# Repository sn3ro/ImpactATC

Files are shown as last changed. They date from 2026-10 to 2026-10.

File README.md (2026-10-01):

# ImpactATC

**Macros, integration examples, and user-modifiable components for the ImpactATC automatic tool changer.**

ImpactATC is a CNC automatic tool change system that uses an **impact driver mechanism** to generate the torque required for tightening and loosening the collet nut. This approach enables higher and more consistent torque compared to typical hobby ATC systems. At its default settings, ImpactATC tightens the ER20 nut to around 35Nm.

This repository provides the **essential files needed to integrate and use ImpactATC**, including CNC macros and selected user-serviceable hardware components.

---

## 📦 What’s in this repository

- CNC macros for tool changing (e.g. LinuxCNC)
- Basic integration examples
- Selected 3D-printable parts for user interfacing (e.g. nut holder)

This repository **does not contain the full mechanical design** of ImpactATC.

---

## 📁 Repository Structure (once all the files are added)

```markdown
ImpactATC/
├─ macros/            # CNC tool-change macros and control logic
│  ├─ linuxcnc/       # LinuxCNC-specific macros (M6, subroutines, HAL)
│  └─ README.md       # Notes on usage and configuration
│
├─ hardware/          # User-modifiable hardware components only
│  ├─ step/           # Printable / reference CAD (e.g. ER20 nut holder)
│  └─ README.md       # Scope, print settings and limitations
│
├─ docs/              # Basic setup and integration guidance
│  └─ setup.md        # Initial setup instructions
│
└─ README.md
```
---

## ⚙️ How It Works

ImpactATC uses a mechanism inspired by an **impact driver**:

- Rotational energy is accumulated and released in controlled impacts  
- These impacts generate high peak torque  
- This enables reliable tightening and loosening of the collet nut  

This method provides improved performance over systems relying on friction or limited mechanical leverage.

---

## 🛠 Getting Started

1. Download the required macros from `macros/`  
2. Print any required parts from `hardware/` — see [`hardware/README.md`](hardware/README.md) for
   materials and print settings (the ER20 nut holder is PETG, Strength profile, 100% infill)  
3. Follow setup instructions in `docs/`  
4. Integrate with your CNC controller  

---

## 🔒 Notes on Design Files

Only a subset of hardware files is included in this repository.

These are provided to:
- Allow integration with ImpactATC
- Enable user modification of interface components

They are **not a complete representation of the system design**.

---

## ⚠️ Safety

ImpactATC involves high torque and dynamic mechanical loading.

- Test carefully at low speeds  
- Ensure all components are securely mounted  
- Use appropriate guarding and PPE  

You are responsible for the safe operation of your machine.

---

## 📜 License

This project is licensed under the **MIT License**.

You are free to use, modify, and adapt the provided files.  
See the `LICENSE` file for details.

---

## 📬 Feedback

If you have questions or suggestions, feel free to open an Issue.

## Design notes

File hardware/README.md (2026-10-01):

# Hardware

User-serviceable parts only. This is **not** the full mechanical design of ImpactATC — see the note
in the top-level [README](../README.md).

## What's here

| File | Part |
|---|---|
| `step/ImpactATC-ER20-Nut-holder.step` | ER20 nut holder |

STEP is supplied rather than STL because slicers such as Bambu Studio and Orca open STEP directly,
and it stays useful if you want to modify the part.

---

## ER20 nut holder

The nut holder transfers torque from the module directly onto the ER20 collet nut.

It is a **wear part**. Expect to replace it after a few hundred tool-change cycles — it is meant to
be the component that wears, so print spares and keep one on the shelf.

### Print settings

| Setting | Value |
|---|---|
| Material | **PETG** |
| Profile | Bambu Studio **Strength** preset |
| Infill | **100%** |

The part is under repeated impact loading, so the 100% infill and the Strength profile both matter —
a standard or draft profile will not survive. Do not substitute PLA.

### Printing it

1. Open `step/ImpactATC-ER20-Nut-holder.step` directly in Bambu Studio (or your slicer of choice).
2. Select the **Strength** profile and a PETG filament.
3. Set infill to **100%**.
4. Slice and print.

### Replacing it

Replacement is covered by the disassembly sequence: remove the top dust cover, lift out the old nut
holder and the spring beneath it, fit the new holder, and reassemble in reverse.

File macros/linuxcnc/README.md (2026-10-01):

# ImpactATC macros for LinuxCNC

The **reference implementation**. The load and unload sequences here are the ones run daily on the
development machine (LinuxCNC on a Remora-converted EC300); every other dialect is ported from them.

---

## Files

| File | Purpose | Needed? |
|---|---|---|
| `impactatc_tool_loading.ngc` | Load a tool — screws the collet nut on | **Yes** |
| `impactatc_tool_unloading.ngc` | Unload a tool — unscrews the collet nut | **Yes** |
| `impactatc_check_loaded.ngc` | Confirms a tool is in the spindle after a load | Optional — needs a beam sensor |
| `impactatc_check_unloaded.ngc` | Confirms the spindle is empty after an unload | Optional — needs a beam sensor |

For automatic changes on `M6`, see [`m6-integration/`](m6-integration/) once these are commissioned.

All four ship as **standalone programs**: open one in AXIS / gmoccapy / QtDragon and run it like any
other program. That is the commissioning step — see [setup.md, stage 5](../../docs/setup.md#5-commission).

---

## Installing

Copy the files into a folder listed in `SUBROUTINE_PATH` in your INI's `[RS274NGC]` section — for
example:

```ini
[RS274NGC]
SUBROUTINE_PATH = macros
```

**Keep the filenames lowercase.** LinuxCNC lower-cases `o<name>` when it looks a subroutine file
up, so a file with capitals in its name cannot be called once you integrate. Don't rename them.

---

## Setting it up

Each macro has a **SET ME** block at the top. The values ship as `9999`, and the macro **aborts
with a message** until you replace them — it will not drive anywhere with placeholder coordinates.

| Parameter | In | What it is |
|---|---|---|
| `#<z_reference>` | load, unload | Machine Z where the spindle, **with no collet nut fitted**, just touches the top face of the module. About −62 on the development machine — yours will differ |
| `#<pocket_x>` / `#<pocket_y>` | load, unload | Machine XY of the pocket centre, measured with the nut fitted |
| `#<sensor_x>`, `#<beam_x>`, `#<sensor_y>`, `#<z_check>` | both checks | Sensor approach position, in-beam X, and the Z where your shortest tool still breaks the beam |
| `#<beam_broken_val>` | both checks | What `#5399` reads with the beam broken. `1` on the development machine; confirm yours in Halshow |

Measure them as described in [calibration.md](../../docs/calibration.md). The load and unload values
**must be identical** — a mismatch is the classic cause of a module that loads and then misses on
unload. The same goes for the two check macros.

Everything else — speeds, feeds, dwells, engagement depths — is the production configuration.
See [parameters.md](../../docs/parameters.md) before changing any of it, and note that the unscrew
speed (1250) is **deliberately** higher than the tightening speed (1100).

---

## Commissioning

Hand on the E-stop throughout. Follow [setup.md](../../docs/setup.md#5-commission); in short:

1. Dry-run the spindle: `M3 S900`, `M3 S1100`, `M4 S300`, `M4 S1250`. **M4 must reverse.**
2. Fill in the SET ME blocks. Run each macro once with values still at `9999` and confirm it aborts —
   that proves the guard works on your install.
3. Walk the Z moves by hand at the pocket, spindle stopped.
4. Run **unload** first, with a nut and tool in the spindle. Then **load**.
5. Alternate them for several cycles and watch for drift.

### Optional: tool presence sensor

The check macros read a through-beam sensor (developed with an Autonics BUP-50 fork sensor) on
`motion.digital-in-00`, using `M66 P0 L0`. Your HAL needs one line; the input pin name depends on
your hardware:

```hal
net tool-present motion.digital-in-00 <= <your-input-pin>
```

`motion.digital-in-00` exists by default (motmod creates four). Then:

1. Open Halshow, watch `motion.digital-in-00`, and break the beam by hand. If broken reads `0`, set
   `#<beam_broken_val> = 0` in both check macros.
2. With a tool loaded, run `impactatc_check_loaded.ngc` — it should complete silently.
3. With the spindle empty, run `impactatc_check_unloaded.ngc` — it should complete silently.
4. Hold a chip or a strip of card in the fork and run either one — it must abort with
   *beam blocked before check*.

A dead sensor stuck at "clear" cannot be caught by the unload check (clear is the expected answer);
the load check catches it on the next load.

---

## Integrating with M6

Only once the standalone macros work reliably.

**Converting a macro to a subroutine:** uncomment the `o<...> sub` and `o<...> endsub` lines and
delete the final `M2`. It can then be called as `o<impactatc_tool_unloading> call` from your
`M6` remap (`REMAP=M6 ... ngc=...` in the INI).

How the development machine does it, and the lessons from doing it:

- **Tool numbering** — manual tools in pockets 1–60, ATC pockets 61 and up. The remap compares the
  current and requested pockets to pick one of four cases: manual→manual, manual→ATC, ATC→manual,
  ATC→ATC. See [tool-numbering.md](../../docs/tool-numbering.md).
- **Pocket coordinates live in the remap**, which moves over the pocket and then calls load or
  unload. With several modules, remove the XY move and the pocket SET ME lines from the load/unload
  subroutines so there is only one copy of each coordinate. Keep `z_reference` in both.
- **Abort on an unknown pocket.** If the requested pocket has no coordinates, the remap must
  `(ABORT, ...)` — never fall back to a default position and run the cycle there. Adding a module
  and forgetting its coordinates should stop the machine, not plunge the spindle somewhere else.
- **Travel along a safe lane.** Retract to safe Z and move along a Y (or X) that clears every
  module before going over the pocket.
- **Call the checks straight after each load / unload**, while still near the changer.
- **Update the tool number after an ATC→ATC change** with `M61 Q<tool>`; the builtin `M6` does it
  in the cases that end in a manual change.
- **After any abort**, LinuxCNC's idea of the loaded tool may be wrong. Fix the physical problem,
  then set the true state with `M61 Q<n>` (`M61 Q0` for an empty spindle) before running anything.

A complete, ready-to-configure remap built on these lessons is in [`m6-integration/`](m6-integration/).

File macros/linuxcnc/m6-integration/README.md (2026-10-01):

# ImpactATC M6 integration for LinuxCNC

An `M6` remap that changes tools automatically between ImpactATC modules, and by hand for any tool
that does not live in a module.

> **Status: for testing.** The sequence is the one used daily on the development machine, but this
> generic package has not yet been through a validation campaign on hardware. It has been run
> through the LinuxCNC 2.9 interpreter in simulation — all four cases, the configuration guards,
> and the sensor and cover options. Commission it with the test sequence below, hand on the E-stop.

> **Do this last.** Only start here once the standalone macros in [`../`](../) load and unload
> reliably on your machine. See [setup.md](../../../docs/setup.md#6-integrate).

---

## What it does

When your program calls `M6`, LinuxCNC runs `impactatc_m6.ngc` instead of its built-in tool change.
It looks at the **P (pocket)** column of the tool table for the tool in the spindle and the tool
requested:

| P | Meaning |
|---|---|
| 1–60 | Manual tool. Changed by hand at the manual change position |
| 61–66 | Lives in that ImpactATC module (61 = first module, 62 = second, …) |

and picks one of four cases:

| Case | What happens |
|---|---|
| manual → manual | Goes to the manual change position, LinuxCNC's normal tool-change prompt |
| manual → ATC | Manual stop to **empty** the spindle (skipped if it is already empty), then the ATC loads the new tool |
| ATC → manual | ATC unloads the current tool, then manual stop to insert the new one (skipped for `T0`) |
| ATC → ATC | ATC unloads into one module, then loads from the other |

Travel to and from the modules goes along a **safe lane** you define, so a tool hanging below the
spindle never passes over a module.

### Safety behaviour

The remap **aborts before anything moves** if:

- any required value in the config is still `9999`
- a tool's P number is 61–66 but that module has no coordinates (or P is above 66)
- an ATC → ATC change has both tools assigned to the **same module** — unloading one and loading
  "the other" would just reload the same tool, with the wrong tool length

With the optional sensor fitted it also aborts if the spindle is not empty after an unload, not
loaded after a load, or the sensor is blocked by a chip.

---

## Files

| File | Edit it? | Purpose |
|---|---|---|
| `impactatc_m6_config.ngc` | **Yes — the only one** | All your machine's values |
| `impactatc_m6_after_change.ngc` | Optional | Your hook, e.g. tool-length measurement |
| `impactatc_m6.ngc` | No | The remap — decides the case and runs it |
| `impactatc_m6_load.ngc` | No | Load sequence (production values) |
| `impactatc_m6_unload.ngc` | No | Unload sequence (production values) |
| `impactatc_m6_pocket_xy.ngc` | No | Pocket lookup — aborts on unknown pockets |
| `impactatc_m6_lane.ngc` | No | Safe-lane travel |
| `impactatc_m6_check.ngc` | No | Optional beam-sensor check |
| `impactatc_m6_cover.ngc` | No | Optional powered cover |
| `python/toplevel.py`, `python/remap.py` | No | Hook LinuxCNC's standard remap glue in |

The load and unload sequences use exactly the same speeds, feeds and depths as the standalone
macros. The Z reference and pocket positions now come from the one config file, so load and unload
can no longer disagree about them.

---

## Requirements

- LinuxCNC **2.8 or later**, with a **non-random** tool changer (`RANDOM_TOOLCHANGER = 0`, the default)
- A working manual tool change — normally `hal_manualtoolchange`, which most configs already load
- **M4 reverses the spindle**, and the standalone macros already commissioned
- If you already remap `M6` (for example with Probe Screen), you will need to merge the two — see
  [Existing M6 remaps](#existing-m6-remaps)

---

## Installing

1. **Copy the `.ngc` files** into a folder inside your config, e.g. `~/linuxcnc/configs/mymill/impactatc/`.
   Do **not** put the standalone macros from `../` in the same folder.
2. **Copy the `python/` folder** into your config folder, and copy LinuxCNC's own `stdglue.py` next
   to the two files in it. Find it with:
   ```sh
   find / -name stdglue.py 2>/dev/null
   ```
   It ships with LinuxCNC (under `remap_lib/python-stdglue/`). If your config already has a
   `python/` folder with `stdglue.py`, keep yours and skip this step.
3. **Edit your INI:**
   ```ini
   [RS274NGC]
   SUBROUTINE_PATH = impactatc
   REMAP = M6 modalgroup=6 prolog=change_prolog ngc=impactatc_m6 epilog=change_epilog

   [PYTHON]
   PATH_PREPEND = ./python
   TOPLEVEL = python/toplevel.py

   [EMCIO]
   RANDOM_TOOLCHANGER = 0
   ```
   If `SUBROUTINE_PATH` already lists folders, add `impactatc` to it with a colon:
   `SUBROUTINE_PATH = macros:impactatc`.
4. **Fill in `impactatc_m6_config.ngc`.** Copy `z_reference` and the pocket XY values you proved
   during standalone commissioning. Then add the safe lane and the manual change position.
5. **Set up the tool table.** Give each ATC tool the P number of the module it lives in:
   ```
   T1   P1   D6.000  Z-25.0  ; manual tool
   T61  P61  D6.000  Z-31.9  ; lives in module 1
   T62  P62  D5.000  Z-24.8  ; lives in module 2
   ```
   Tool numbers do not have to match P numbers. Several tools may share a module's P number if you
   swap them in and out by hand, but **the table must always say which tool is physically in each
   module** — the ATC cannot tell them apart.

---

## The config values

| Value | What it is |
|---|---|
| `_atc_z_reference` | Machine Z, spindle **without nut** touching the module top. One value for all modules |
| `_atc_pocket_61_x` … `_66_y` | Pocket centre per module, measured with the nut fitted. Unused = `9999` |
| `_atc_z_safe` | Safe Z for all travel. Normally `0` |
| `_atc_lane_axis`, `_atc_lane` | Modules in a row along X → `0` and a Y that clears them all. Along Y → `1` and an X |
| `_atc_manual_x/y/z` | Where the spindle waits for a manual tool change |
| `_atc_use_sensor` … | Optional beam sensor — same meaning as in the standalone check macros |
| `_atc_use_cover` … | Optional powered cover on a digital output (`M64`/`M65`) |

Measure positions as described in [calibration.md](../../../docs/calibration.md).

---

## Commissioning

Hand on the E-stop. Do not stand in line with the modules. Work through these in order. Before
each test, set LinuxCNC's tool state to match reality with `M61 Q<tool>` (`M61 Q0` = spindle empty).

| # | Starting state | Command | Expect | Watch for |
|---|---|---|---|---|
| 1 | Config still at 9999 | `T61 M6` | Immediate abort, **no motion** | Any movement at all = stop |
| 2 | Config filled; add a test tool `T99 P67` | `T99 M6` | Abort: pocket not configured, **no motion** | |
| 3 | Spindle empty, `M61 Q0` | `T61 M6` | Lane → module 1 → load → lane | Path along the lane is clear; tool is tight |
| 4 | T61 loaded | `T1 M6` (manual tool) | Unload into module 1 → manual position, prompt | Nut left in module 1, spindle empty |
| 5 | T1 in by hand | `T61 M6` | Message to **empty** the spindle, prompt, then load | Prompt says "insert T61" — empty the spindle anyway |
| 6 | T61 loaded, second module fitted | `T62 M6` | Unload 61, load 62 | Lane used between modules |
| 7 | Two tools set to the same P | change between them | Abort: same module | |
| 8 | Any ATC tool loaded | `T0 M6` | Unload, spindle left empty, no prompt | |

Repeat tests 3, 4 and 6 for several cycles and watch for drift. With the sensor enabled, also run
test 3 with a strip of card in the beam: it must abort with *beam blocked*.

---

## After an abort

An abort stops the program where it is. The cover, if powered, is left open so you can get at the
module. LinuxCNC's idea of which tool is loaded **may now be wrong**:

1. Clear the physical problem.
2. Tell LinuxCNC the truth: `M61 Q<tool in spindle>`, or `M61 Q0` if it is empty.
3. Only then run anything else.

See [troubleshooting.md](../../../docs/troubleshooting.md#recovering-after-a-failed-change).

---

## Your program

- After `M6`, the spindle is **stopped** and **no tool length offset is applied**. Your program must
  restart the spindle and issue `G43 H..` after `M6`. Most CAM post-processors do both already.
- Re-measuring tool length after each ATC load is recommended — put your tool-setter routine in
  `impactatc_m6_after_change.ngc`.

---

## Existing M6 remaps

LinuxCNC allows only one `M6` remap. If you already have one — Probe Screen's
`psng_manual_change`, for example — you have two choices:

- **Replace it** with this one and call your measurement from `impactatc_m6_after_change.ngc`.
- **Keep yours** and copy the case logic from `impactatc_m6.ngc` into it, calling the same
  `impactatc_m6_*` subroutines. This is how the development machine is set up.

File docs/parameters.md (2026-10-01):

# Parameters

Every value the macros use, what it does, and when changing it is justified.

The defaults are not arbitrary. They came out of a long series of logged tests, and several of them
sit close to a limit where the module stops working or starts damaging itself. Read the notes before
changing anything.

---

## Spindle speeds

| Parameter | Default | What it does |
|---|---|---|
| `rpm_engage` | **900** | Speed while threading the nut on, before tightening |
| `rpm_tighten` | **1100** | Final tightening speed. Sets clamping torque — about **35 Nm** |
| `rpm_unscrew` | **1250** | Speed for unscrewing |
| `rpm_settle` | **300** | Gentle rock either way to seat the nut holder on the nut before unscrewing |

### Why unscrew is faster than tighten

This asymmetry is deliberate and it surprises people.

A nut tightened at 1100 rpm can work itself **tighter** during cutting. Unscrewing at the same speed
that tightened it does not reliably break it loose. Running unscrew 150 rpm higher gives the headroom
to release those tools.

> **Never harmonise the two values.** If you raise the tightening speed, raise the unscrew speed to
> keep the margin.

### Changing `rpm_tighten`

This is the parameter people most want to change, because it sets clamping torque. Two cautions:

- **Higher is not automatically better.** Torque comes from impact energy, and the mechanism has a
  speed at which engagement stops being clean. Past that, cycles start failing — and on earlier
  hardware, running too fast destroyed the engagement teeth outright.
- **Change it in small steps and watch.** Raise by 50 rpm, run several cycles, and look at the
  parts. The failure mode is gradual and then sudden.

If you are not getting enough clamping force, check `z_reference` and the engagement depths before
reaching for the speed. A partly engaged nut holder will never tighten properly no matter how fast
it spins.

---

## Feeds

| Parameter | Default | What it does |
|---|---|---|
| `feed_slow_z` | **1000** (load) / **900** (unload) | Z feed while engaging the nut |
| `feed_fast_z` | **2400** | Z feed for positioning moves |

The engagement feed is a compromise. Too slow and the nut has time to bind as it threads; too fast
and the holder can skip over the nut instead of dropping onto it. The load and unload values differ
slightly because the two operations are not symmetric — loading threads a nut on, unloading has to
seat a holder onto a nut that is already tight.

---

## Dwells

| Parameter | Default | What it does |
|---|---|---|
| `dwell_tighten` | **2.0 s** | Time held at tightening speed |
| `dwell_unscrew` | **2.0 s** | Time held at unscrewing speed |
| `dwell_settle` | **0.3 s** | Each pause during the seating rock |
| `dwell_stop` | **1.0 s** | Time allowed for the spindle to come to rest |

The two long dwells have to cover **spindle spin-up plus the work itself**. If your spindle ramps
slowly, the dwell may expire while it is still accelerating, and the cycle will under-perform without
any obvious error. See below.

`dwell_stop` matters more than it looks: retracting while the spindle is still turning down can drag
the nut.

---

## Positions

| Parameter | Default | What it does |
|---|---|---|
| `z_reference` | **−62** | Machine Z where the bare spindle face touches the module top. **Machine-specific** |
| `z_engage_offset` | **16** | How far above the reference the descent begins |
| `z_nut_thread` | **−31** | Incremental plunge that threads the nut on (load) |
| `z_nut_contact` | **−24** | Incremental first step down onto the nut (unload) |
| `z_nut_seat` | **−5** | Incremental second step, fully seating the nut (unload) |
| `pocket_x` / `pocket_y` | — | Machine XY of the pocket. **Machine-specific** |

`z_reference`, `pocket_x` and `pocket_y` are yours to measure — see [calibration.md](calibration.md).
The rest describe the module's own geometry and should not need changing.

Note that unloading descends in **two steps** with a seating rock between them, while loading
descends in **one**. Unloading has to persuade a holder onto an already-tight nut; loading starts
with a nut sitting loose in the changer.

---

## Spindle ramp times

Not a macro parameter — a VFD setting — but it affects whether the macros work.

The long dwells assume the spindle reaches commanded speed within them. A VFD configured with a
10-second ramp will still be accelerating when a 2-second dwell expires.

Symptoms of a ramp that is too slow:
- Weak or inconsistent clamping
- The opening sequence failing to start, as if the spindle lacks torque

On the development machine, acceleration and deceleration were reduced to roughly **4 s up / 5 s
down** from a 10 s default. Consult your VFD manual for the equivalent parameters. Do not set them
so aggressively that the drive trips.

---

## Controller minimum speed

The sequence commands 300 rpm during the seating rock. Check that both your VFD and your controller
will actually deliver it:

- VFDs have a minimum output frequency, often set well above idle
- Controllers usually have a minimum spindle speed setting, below which they clamp or refuse

If 300 rpm is not achievable, the rock does nothing and the holder may not seat — which shows up as
unreliable unloading.

---

## Summary table

Quick reference for a working configuration.

```
rpm_engage      = 900
rpm_tighten     = 1100        ; ~35 Nm
rpm_unscrew     = 1250        ; deliberately > rpm_tighten
rpm_settle      = 300

feed_slow_z     = 1000 / 900  ; load / unload
feed_fast_z     = 2400

dwell_tighten   = 2.0
dwell_unscrew   = 2.0
dwell_settle    = 0.3
dwell_stop      = 1.0

z_reference     = machine-specific   ; measure it
pocket_x        = machine-specific   ; measure it
pocket_y        = machine-specific   ; measure it
z_engage_offset = 16
z_nut_thread    = -31
z_nut_contact   = -24
z_nut_seat      = -5
```

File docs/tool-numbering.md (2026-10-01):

# Tool numbering

Once some tools live in the changer and some are still changed by hand, the controller needs to know
which is which. This is the convention used on the development machine.

---

## The convention

| Tool numbers | Meaning |
|---|---|
| **1 – 60** | Manual tools. The machine stops and asks you to change them |
| **61 and up** | ATC tools. The machine fetches them from a pocket automatically |

The tool change logic then reduces to a single test: *is the tool number above 60?*

## Why a number range rather than a flag

Controllers vary in how much they will let you annotate a tool. Many will not let you attach an
arbitrary "this one is automatic" flag to a tool table entry, and those that do often express it
through pocket assignment, which brings its own constraints.

A number range needs no support from the controller at all. It works on any of them, it survives
tool table edits, and it is obvious at a glance which kind of tool you are looking at. The cost is
that you have to remember the rule — hence writing it down here.

Pick a boundary that suits your shop. 60 is arbitrary; what matters is that it is well above the
number of manual tools you will ever have, and that you never cross it by accident.

---

## What this buys you

With the ranges in place, a tool change falls into one of four situations:

| | Current tool | New tool | What must happen |
|---|---|---|---|
| **1** | Manual | Manual | Normal manual change. The changer is not involved |
| **2** | Manual | ATC | Manual unload by hand, then automatic load from a pocket |
| **3** | ATC | Manual | Automatic unload to a pocket, then manual load by hand |
| **4** | ATC | ATC | Automatic unload to one pocket, automatic load from another |

Situation 4 is the one that pays for the changer. Situations 2 and 3 are the awkward middle ground
and are easy to forget when writing the logic — they are also where most integration bugs live.

---

## Pockets

Each ATC tool needs to know which pocket it lives in. How you express that depends on the
controller; in LinuxCNC it is the pocket column of the tool table.

> **One tool per pocket.** A pocket physically holds one tool. If the tool table claims two tools
> share a pocket, the controller will happily fetch whatever is actually there and then apply the
> *other* tool's length offset. That error goes straight into the work, and it can be several
> millimetres.
>
> If you swap tools in and out of a pocket as a matter of practice, keep the tool table honest at
> the same time — or accept that the length offset is only correct for whichever tool is currently
> fitted.

---

## Practical notes

- **Leave gaps.** Numbering pockets 61, 62, 63 and tools to match is tidy until you add a fourth.
- **Name your tools** in the tool table comment, including which are ATC tools. On the development
  machine the ATC entries are prefixed `ATC -` so they are obvious in a list.
- **Re-measure tool length after every automatic change.** The module clamps consistently, but a
  tool can sit slightly differently in the collet. Most setups probe against a tool setter as part
  of the change.

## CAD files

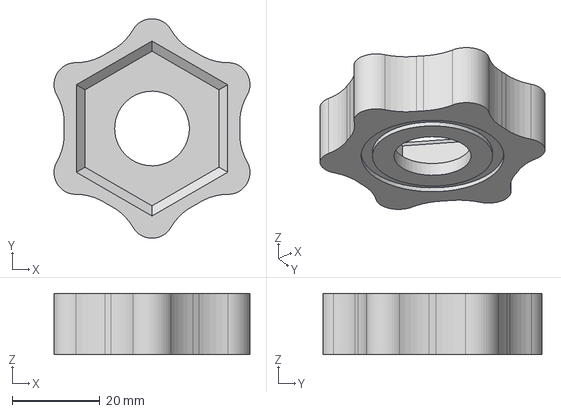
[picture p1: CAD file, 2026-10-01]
hardware/step/ImpactATC-ER20-Nut-holder.step
44.6 x 50.0 x 14.0 mm

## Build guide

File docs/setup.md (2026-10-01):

# Setup and integration

How to get ImpactATC working on your machine, from unpacking to an automatic tool change.

Work through the stages in order. Each one is verifiable on its own, and stopping between them
costs nothing. The single most common cause of trouble is skipping ahead to a full cycle.

| Stage | You end up with | Time |
|---|---|---|
| [1. Check your machine suits it](#1-check-your-machine-suits-it) | Confidence it will work at all | 15 min |
| [2. Mount the module](#2-mount-the-module) | Module bolted down, spindle able to reach it | 30 min |
| [3. Calibrate](#3-calibrate) | Your Z reference and pocket coordinates | 30 min |
| [3b. Set up the VFD](vfd-setup.md) | A spindle that can actually turn the nut | 30 min |
| [4. Install the macros](#4-install-the-macros) | Macros on the machine with your values in them | 15 min |
| [5. Commission](#5-commission) | Load and unload working, run by hand | 1 hr |
| [6. Integrate](#6-integrate) | `M6` doing it automatically | 1–2 hr |

---

## 1. Check your machine suits it

ImpactATC drives the collet nut with the spindle itself. That puts a few hard requirements on the
machine, and it is much cheaper to find a blocker now than after mounting.

| Requirement | Why | Typical blocker |
|---|---|---|
| **ER20 collet nut** | The module is built around it | ER11/ER16/ER25 spindles need a different module |
| **Spindle reverse (M4)** | Unloading unscrews counter-clockwise | Many router/VFD setups are wired CW-only. **Check this first** |
| **Stable running at 300–1250 rpm** | The sequence uses 300, 900, 1100 and 1250 rpm | VFD minimum frequency set too high; controller minimum RPM setting |
| **Reasonably brisk spindle accel/decel** | The sequence relies on reaching speed within the dwell | VFD ramp times of 10 s+ will not keep up — see [vfd-setup.md](vfd-setup.md) |
| **Low-speed torque** | Everything happens below 5% of a 24 000 rpm spindle's range | Most VFDs need configuring for this. **[vfd-setup.md](vfd-setup.md) is not optional reading** |
| **Z travel below the module top** | Engagement happens roughly 46 mm below the reference | Short-Z machines, or soft limits set tight |
| **Somewhere to put it** | The module needs a clear XY position plus an approach path | Small tables, or fixtures in the way |

> **Test M4 before you do anything else.** Command `M4 S300` at the machine and confirm the spindle
> turns *backwards*. If it does not, unloading cannot work and everything below is wasted effort.

---

## 2. Mount the module

Bolt the module to the table where the spindle can reach it and where it will not foul your normal
work. Points that matter:

- **Rigid mounting.** The module generates high peak torque in short impacts. Anything springy
  will absorb the impacts instead of transmitting them to the nut.
- **Clear approach.** The spindle arrives from above and descends. Check the whole descent is clear,
  including with your *longest* tool fitted.
- **Away from the work.** Chips and coolant will find it. A position outside the normal working
  envelope is worth the lost table space.
- **Think about the retract path now.** After a change, the spindle lifts and travels away. On a
  machine with several pockets, plan a safe Y or X lane the spindle can use to get between them
  without crossing anything.

---

## 3. Calibrate

You need three numbers, all in **machine coordinates**: the Z reference, and the X and Y of the
pocket. Full method in [calibration.md](calibration.md).

The short version:

- **Z reference** — take the collet nut *off*, jog the spindle down until it just touches the top
  face of the module, and read machine Z. The nut is removed on purpose: the bare spindle face is a
  hard, repeatable surface anyone can find without knowing anything about our machine.
- **Pocket X and Y** — jog until the spindle is centred over the module, and read machine X and Y.

Write them down. You will put the same values into more than one file.

---

## 4. Install the macros

Pick your controller:

| Controller | Location | Notes |
|---|---|---|
| **LinuxCNC** | [`macros/linuxcnc/`](../macros/linuxcnc/) | Reference implementation. Files go in the folder named by `SUBROUTINE_PATH` in your INI |

Put your three calibration numbers into the **SET ME** block at the top of each macro. They must be
**identical in both** the load and unload macros — a mismatch is the classic cause of a module that
loads fine and then misses on unload.

---

## 5. Commission

**Hand on the E-stop for all of this.** Do not stand in line with the module.

1. **Dry-run the spindle.** Nothing in the module. Confirm `M3 S900`, `M3 S1100`, `M4 S300` and
   `M4 S1250` all behave, and that M4 genuinely reverses.
2. **Walk the moves by hand.** Jog to the pocket, then jog down through the engage height and the
   incremental steps. Confirm the nut holder lines up with the nut and nothing collides.
3. **Unload first.** Start with a nut and tool fitted in the spindle and run the unload macro.
   Unloading is the gentler operation and failure is more obvious — the nut simply does not come off.
4. **Then load.** With the nut sitting in the changer, run the load macro.
5. **Repeat.** Alternate the two and watch for drift. If something is marginal, it shows up over
   cycles rather than on the first one.

If any step misbehaves, stop and read [troubleshooting.md](troubleshooting.md) rather than adjusting
parameters hopefully. Most failures have one specific cause.

---

## 6. Integrate

Only once both macros work reliably on their own.

The macros ship as **standalone programs** on purpose. That is the commissioning form: you can run
one, watch it, and stop. Integration is the second step, when you already trust the sequence.

To integrate, you wrap the sequences in your controller's tool-change mechanism so that `M6` calls
them. That means deciding:

- **Which tools live in the changer** and which are still changed by hand — see
  [tool-numbering.md](tool-numbering.md) for the convention that keeps the two apart
- **What happens between pockets** — the safe travel path
- **How tool length is handled** — most people re-measure with a tool setter after each change
- **What happens when it goes wrong** — see [troubleshooting.md](troubleshooting.md#recovering-after-a-failed-change)

For LinuxCNC, a ready-to-configure `M6` remap covering all four situations (manual→manual,
manual→ATC, ATC→manual, ATC→ATC) is in [`macros/linuxcnc/m6-integration/`](../macros/linuxcnc/m6-integration/).
It is marked **for testing** until validated on hardware.

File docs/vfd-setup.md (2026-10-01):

# VFD and spindle setup

ImpactATC drives the collet nut with the spindle motor. That asks something of the spindle it was
never designed for: **high torque at very low speed**, from a standing start, repeatedly.

Out of the box, most VFDs cannot do it. This is the single most common reason a module loads fine
and then fails to unscrew.

> Parameter numbers below are for a **Huanyang HY-series** inverter (the HY02D223B, 2.2 kW / 220 V,
> is the one both the development machine and the first production installs use). Other makes use
> different numbering — the *concepts* transfer, the numbers do not. Check them against your manual.

---

## Why the spindle struggles

A 24,000 rpm spindle reaches full speed at 400 Hz. The tool change sequence runs at:

| Operation | Speed | Drive frequency | % of range |
|---|---:|---:|---:|
| Seating rock | 300 rpm | 5 Hz | 1.3% |
| Threading the nut on | 900 rpm | 15 Hz | 3.8% |
| Tightening | 1100 rpm | 18 Hz | 4.6% |
| Unscrewing | 1250 rpm | 21 Hz | 5.2% |

Everything happens in the **bottom 5%** of the drive's range. A basic V/F inverter delivers its
worst torque exactly there — output voltage scales with frequency, so at 18 Hz the motor sees a
fraction of the voltage it needs to produce torque.

The fix is not to spin faster. It is to configure the drive to deliver torque down there.

---

## The four parameters that matter

Change these in order. After each one, try an unload cycle.

### PD014 / PD015 — acceleration and deceleration time

| | |
|---|---|
| **PD014** | Accel time 1 — seconds from 0 to full speed |
| **PD015** | Decel time 1 — seconds from full speed to 0 |
| **Factory** | Often 10 s or more |
| **Set to** | **PD014 = 4**, **PD015 = 5** as a starting point |

A 10-second ramp means the spindle is still accelerating when the macro's 2-second dwell expires.
The impacts that should be happening at 1100 rpm happen at whatever speed it reached — which may be
nothing like enough.

Shortening the ramp also gives noticeably more torque breaking away from standstill, which is what
the unscrew sequence needs most.

> **Do not go too aggressive.** A very short ramp draws a large current spike and will trip the
> inverter's over-current protection. Come down in steps and stop when it works reliably.

### PD142 — rated motor current

Set this to the **rated current printed on your spindle**, in 0.1 A units. On a typical 2.2 kW
air-cooled spindle this is around 8 A.

The inverter uses this to limit its output and protect the motor. Set too low, the drive protects
itself *before* delivering the current the module needs, and the spindle stalls while the inverter
believes it is doing the right thing.

### PD120 — stall prevention at constant speed

| | |
|---|---|
| **Set to** | **0** (disabled) |

This one is counter-intuitive, and it is worth understanding rather than just copying.

When enabled, if current rises past the configured level at constant speed, the inverter **lowers
its output frequency** until current returns to normal.

That behaviour is correct for a fan or a pump. It is exactly wrong here. Unscrewing a tight nut
*is* a current spike — that is the whole operation. Stall prevention sees it, drops the frequency,
and the impacts lose the speed they need. The drive fights the very thing you are asking it to do.

Setting PD120 to 0 disables it. Factory setting is already 0 on many units; check rather than assume.

### PD145 — auto torque compensation

| | |
|---|---|
| **Factory** | 2.0% |
| **Set to** | **3**, then raise gradually |

This is the parameter that solves low-speed torque directly. It adds extra output voltage at low
frequency to compensate for the under-torque a V/F drive produces there.

**Raise it slowly, one step at a time, testing between each.** The manual is explicit about why:
too little and the motor stays under-torqued at low speed; too much produces a mechanical shock to
the machine and can trip the inverter outright.

On the first production install, 3 improved things immediately and 4 was better still.

---

## Recommended starting point

| Parameter | Value | Purpose |
|---|---|---|
| PD014 | 4 s | Accel time |
| PD015 | 5 s | Decel time |
| PD120 | 0 | Stall prevention off |
| PD142 | Your spindle's rated current | Correct current limit |
| PD145 | 3, raised gradually | Low-speed torque compensation |

Also confirm **PD143** (motor poles) and **PD144** (rated revolution) match your spindle's
nameplate — these affect whether the displayed speed means anything.

---

## Check commanded speed against actual speed

**Do this before you tune anything else.** It has caused real confusion.

The RPM in the macro is what the *controller* asks for. What the spindle actually turns at depends
on the controller's speed scaling, the VFD configuration, and whether they agree. They often do not.

Set the VFD display to show RPM, run the unload macro, and read the display while it spins. If the
macro says 1250 and the drive says something else, fix that mismatch first — otherwise you are
tuning against a number that does not mean what you think it does.

---

## Watch for a controller-side spindle delay

Separately from the VFD, many controllers insert their own dwell after a spindle command, to let it
reach speed before cutting.

That setting is helpful for milling and harmful here. The macros already contain their own dwells,
carefully sized. An extra 4-second delay on every spindle command stretches a tool change out
enormously and can leave the spindle turning at the wrong point in the sequence.

On the first RosettaCNC install, a 4-second controller spindle delay had to be removed before the
timings made any sense.

---

## If it still stalls

In order:

1. **Confirm PD145 is doing something.** Raise it a step and listen — the change at low speed is
   audible. If nothing changes, you may be editing a parameter the drive is ignoring because it is
   in the wrong control mode.
2. **Confirm PD142 is not throttling you.** A value well below the spindle's actual rating limits
   output current directly.
3. **Confirm PD120 is 0.** Stall prevention undoes everything else.
4. **Shorten PD014 further**, one step at a time, until the inverter complains.
5. **Only then raise the unscrew RPM.** More speed is the crude fix; the parameters above are the
   real one. See [parameters.md](parameters.md) — and never raise unscrew above the point where the
   mechanism engages cleanly.

---

## Related

- [parameters.md](parameters.md) — the macro-side speeds, feeds and dwells
- [troubleshooting.md](troubleshooting.md) — symptoms and causes across the whole system

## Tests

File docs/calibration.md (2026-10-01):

# Calibration

You need three numbers before the macros will do anything useful, all in **machine coordinates**
(the coordinate system `G53` works in, not your work offset):

| Value | What it is |
|---|---|
| `z_reference` | Machine Z where the bare spindle face just touches the top of the module |
| `pocket_x` | Machine X of the pocket centre |
| `pocket_y` | Machine Y of the pocket centre |

Everything else the macros do is derived from these.

---

## Why the reference point is defined this way

`z_reference` is measured with the **collet nut removed**, with the spindle's bare face touching
the top face of the module.

That looks awkward the first time. It is deliberate: the bare spindle face and the module's top
face are both hard, flat and repeatable. Anyone can find that point on any machine without knowing
anything about the machine it was designed on, and without depending on a particular nut, collet or
tool. Every other height the macros use is an offset from it.

If instead the reference were "nut fitted, touching something", it would shift with nut wear, collet
choice and how far the tool sticks out — and it would not transfer between machines at all.

---

## Finding `z_reference`

1. **Home the machine.** All of this is in machine coordinates, so homing must be reliable first.
2. **Remove the collet nut** from the spindle completely. No nut, no collet, no tool.
3. **Jog the spindle over the module** and roughly centre it.
4. **Jog down in decreasing steps** — 1 mm, then 0.1 mm, then 0.01 mm — until the spindle face just
   touches the top face of the module. A strip of paper is the usual trick: jog down until the paper
   just binds.
5. **Read machine Z** and write it down. On the development machine this is about **−62**; yours
   will differ.

> **Do not guess this.** Too high and the nut holder never engages the nut. Too low and the spindle
> drives down into the module — on the first production install, a reference set too deep **broke
> the centre component of a module**. It takes five minutes to measure and it is the number
> everything else hangs off.

If a module starts making a noise it did not make before, or a cycle ends with the spindle further
down than you expected, stop and re-check this value before running another cycle.

---

## Finding `pocket_x` and `pocket_y`

Note the difference from the Z reference: this one is measured **with the collet nut fitted**.

1. **Fit the nut** to the spindle.
2. **Jog the spindle over the module** at a safe height.
3. **Lower the spindle so the nut sits about halfway into the nut holder.** Not all the way down —
   halfway is enough to judge the fit.
4. **Centre it.** Push the module gently sideways in each direction; there should be a little play
   all the way around, and it should be even. That even play is your centre, and it is a far more
   reliable judgement than eyeballing the bore from above.
5. **Bolt the module down** so it cannot move, then **read machine X and Y**.

Do this for every module. Keep the values in a table and label them clearly — transposing two
pockets is an easy mistake with an expensive result.

### Spacing multiple modules

The module body is **95 mm**. Spacing them on **100 mm centres** works well and leaves room to get
a hand in.

Do not assume the spacing is exact and derive the other pockets arithmetically. Calibrate **each
module individually** — small differences in mounting add up, and a pocket that is 2 mm out is a
pocket that will eventually miss.

---

## Checking your numbers before you trust them

Do this with the **spindle stopped** and your hand on the E-stop. You are checking geometry, not
function.

1. Jog to `pocket_x` / `pocket_y` at a safe Z.
2. Jog down to `z_reference + 16` — the height the macros descend to before engaging. The spindle
   should be clearly above the nut with room to spare.
3. Continue down slowly, by hand, through the engagement depth. Watch the nut holder meet the nut.
   It should drop onto the nut flats, not perch on top of them.
4. Retract.

If the holder sits on top of the flats rather than dropping over them, that is normal — it is what
the seating rock at the start of the unload sequence is for.

---

## Putting the values in

Both the load and the unload macro have a **SET ME** block at the top. Put the same three numbers in
**both files**.

```gcode
#<z_reference>     = -62        ; SET ME
#<pocket_x>        = 0          ; SET ME
#<pocket_y>        = 0          ; SET ME
```

The LinuxCNC macros ship with all three set to `9999` and refuse to run until you replace them.
Other dialects ship with the placeholders above and cannot check — be careful there.

A mismatch between the two files is the classic cause of a module that loads correctly and then
misses on unload. If you change one, change the other in the same sitting.

> This is not a hypothetical. On the first production install, the reference was updated in the
> loading macro but not the unloading one. Loading worked; unloading drove to the old height and
> failed. If unloading misbehaves immediately after you have changed something, check this first.

---

## When to re-calibrate

- After moving or re-mounting the module
- After anything that changes your homing — a crash, a new home switch, a changed home offset
- After changing the spindle or its mounting
- If loads start to feel inconsistent, re-check `z_reference` before changing any other parameter

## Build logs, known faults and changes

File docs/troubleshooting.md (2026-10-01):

# Troubleshooting

Symptoms, their usual causes, and what to check first. Work down each list in order — the entries
are ordered by how often they turn out to be the problem.

> **Before changing any parameter,** re-check `z_reference`. A drifted reference produces symptoms
> that look like a dozen different problems, and adjusting speeds to compensate only hides it.

---

## The nut will not unscrew

**The spindle turns but the nut stays put.**

1. **M4 is not actually reversing.** Command `M4 S300` on its own and watch. Many router and VFD
   setups are wired clockwise-only, in which case unloading cannot work. This is the most common
   blocker on a new installation.
2. **The spindle stalls instead of turning.** If it tries and gives up, this is a VFD configuration
   problem, not a macro problem. Work through [vfd-setup.md](vfd-setup.md) — low-speed torque
   compensation, stall prevention and the current limit all have to be right before the module can
   do its job.
2. **The nut is tighter than it was tightened.** Nuts work themselves tighter during cutting. Confirm
   `rpm_unscrew` is at 1250 and has not been "tidied up" to match the tightening speed.
3. **The holder is not fully seated on the nut.** It is perching on the nut flats rather than
   dropping over them. Check the seating rock is happening — you should see the spindle twitch
   either way before it unscrews — and that 300 rpm is actually achievable on your setup.
4. **Not descending far enough.** Check `z_reference`, then the two incremental steps.
5. **Spindle ramp too slow.** The dwell expires before the spindle reaches speed. See
   [vfd-setup.md](vfd-setup.md).
6. **The Z reference was changed in only one macro.** Loading and unloading each carry their own
   copy. Changing one and not the other produces exactly this symptom.
7. **Commanded RPM is not actual RPM.** Set the VFD to display RPM and check what the spindle really
   turns at. Tuning against a number the drive is not honouring wastes a lot of time.

---

## It unloads on an idle machine but not after cutting

**Tool changes work fine when you test them, then fail once you have actually been cutting.**

The nut works itself **tighter during machining**. This is real and has been observed by more than
one user — a module that changes tools happily all afternoon on an idle machine can refuse to
release the first tool after a real job.

In order:

1. **Raise the unscrew RPM** so it sits meaningfully above the tightening RPM. This is the whole
   reason the two are asymmetric — see [parameters.md](parameters.md#why-unscrew-is-faster-than-tighten).
2. **Lengthen the unscrew dwell** from 2.0 s to 3.0 s, giving the impacts longer to break it loose.
3. **Clean the spindle thread and the inside of the spindle cone.** Dust packs into the thread over
   a job and makes it progressively harder to release. This appears to be worse when cutting **wood**
   than metal — fine dust behaves differently from chips.
4. **A trace of grease on the spindle thread.** Very little. Enough to keep debris from binding in it.

---

## The nut does not tighten enough

**The tool comes loose during cutting, or pulls out.**

1. **Partial engagement.** A holder that is not fully on the nut cannot transmit torque no matter
   how fast it spins. Check `z_reference` and the engagement depth before touching speeds.
2. **Spindle ramp too slow.** Same cause as above: the dwell expires mid-acceleration, so the
   impacts never happen at full speed.
3. **Worn nut holder.** It is a wear part. After a few hundred cycles the drive features round off
   and it slips. Fit a new one — see [hardware](../hardware/README.md).
4. **`rpm_tighten` reduced.** Confirm it is at 1100.
5. **Collet or nut in poor condition.** The module can only tighten what it is given. A worn collet
   or a galled nut thread will not clamp properly.

---

## The tool creeps up in the collet

Observed over many cycles: the tool gradually moves **towards Z+**, out of the collet.

This is expected behaviour rather than a fault, and it is counter-intuitive the first time you see
it. Re-measure tool length after each automatic change rather than trusting a stored offset — most
setups probe against a tool setter as part of the change sequence.

---

## Every step takes far too long

**The sequence works, but each move crawls and the whole change takes an age.**

Look for a **spindle delay in your controller** — a dwell it inserts after every spindle command so
the spindle can reach speed before cutting. Sensible for milling; harmful here, because the macros
already contain their own dwells sized for the job. On the first RosettaCNC install a 4-second
controller delay was being added to every spindle command.

Also check whether your controller's **return-to-position move after a tool change** is using the
last feed rate rather than a rapid. If the last motion was a slow probing move, the return crawls.

---

## The cycle locks up partway through

**The assembly jams, or the sequence stalls mid-cycle.**

1. **Tightening speed too high.** Past a certain speed the mechanism can lock itself during
   threading. If you have raised `rpm_tighten`, put it back to 1100.
2. **Engagement feed wrong.** Too fast and the holder skips over the nut instead of dropping onto
   it; too slow and the nut has time to bind while threading.
3. **Debris in the module.** Chips in the mechanism change how everything moves. Check the chip
   covers are fitted and doing their job.

---

## Damage to the engagement features

**Visible wear or deformation on the drive teeth.**

The nut holder is *designed* to be the part that wears. Damage there after a few hundred cycles is
normal — replace it.

Damage anywhere else, or damage to a holder after only a few cycles, means something is wrong:
almost always a tightening speed that has been raised past what the mechanism tolerates. On earlier
hardware, over-speeding destroyed the engagement features outright in a single cycle.

**Damage to the centre of the module** is a different fault with a different cause: the spindle is
descending too far. Re-measure `z_reference` — see [calibration.md](calibration.md). A reference set
too deep has broken a module in the field.

---

## The spindle will not start the opening sequence

**It stalls instead of breaking the nut loose.**

The spindle does not have enough torque at the moment it needs it. Speed up the VFD ramp so it
reaches the commanded speed faster — see [parameters.md](parameters.md#spindle-ramp-times). On the
development machine, going from a 10-second ramp to roughly 4 s up / 5 s down fixed exactly this.

---

## It worked and now it does not

Something changed. In rough order of likelihood:

1. **Homing.** A crash, a knocked home switch, or an edited home offset moves every machine
   coordinate, including `z_reference` and the pocket. Re-home and re-check.
2. **Worn nut holder.** Consumable, and the decline is gradual enough to be easy to miss.
3. **The module moved.** Check the mounting bolts.
4. **A parameter was edited.** Compare against the summary in
   [parameters.md](parameters.md#summary-table).
5. **Debris.** Chips where they should not be.

---

## Recovering after a failed change

If a tool change fails partway, the machine's idea of what is in the spindle can disagree with
reality. That disagreement is dangerous: the next move may be planned around a tool that is not
there, or not planned around one that is.

1. **Stop.** Do not resume the program.
2. **Look at the machine.** Establish what is physically in the spindle and what is in each pocket.
3. **Clear the problem by hand** — remove a stuck tool, clear chips, undo a half-threaded nut.
4. **Tell the controller the truth.** Set the current tool to match reality before running anything
   else. In LinuxCNC that is `M61 Q<n>`, with `M61 Q0` for an empty spindle.
5. **Re-measure tool length** before cutting again.

Only then resume. Restarting a program without correcting the tool state is how a failed change
turns into a crash.

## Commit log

2026-10-01 Add ER20 nut holder STEP and print guidance
    Adds the ER20 nut holder as STEP under hardware/step/ - slicers such as
    Bambu Studio open STEP directly, and it stays editable.
    hardware/README.md documents it as a wear part and records the required
    print settings: PETG, Bambu Studio Strength profile, 100% infill. The part
    sees repeated impact loading, so lighter profiles are not adequate.
    [ImpactATC-ER20-Nut-holder.step]
2026-10-01 Promote docs and LinuxCNC macros from staging
    Brings docs/ and macros/linuxcnc/ over from ImpactATC-dev main:
    - Setup, calibration, parameters, VFD, tool numbering and
    troubleshooting guides
    - Standalone LinuxCNC load/unload macros renamed to lowercase, with SET ME
    guards; development-machine coordinates and dev moves removed
    - Optional beam-sensor check macros
    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
2026-10-01 Fix M6 remap aborting on T0 M6 with an ATC tool loaded
    On a non-random tool changer, LinuxCNC reports the LOADED tool's pocket
    as #<_selected_pocket> for T0 (index 0 is the spindle slot, which holds a
    copy of the loaded tool). With an ATC tool loaded, T0 M6 therefore looked
    like an ATC->ATC change within the same module and aborted, so a tool
    could never be put away to leave the spindle empty.
    Classify by tool number as well as pocket: tool 0 is never an ATC tool.
    Found by running the package through the LinuxCNC 2.9 interpreter (rs274)
    in simulation: 31 scenarios covering all four cases, configuration guards,
    sensor and cover options, modal-state hand-back and an X-axis lane. Before
    this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
2026-10-19 Add tool retention guide and TPU retention rings (3-13 mm)
    Tools above ~4 mm can slide in the collet while the nut is being turned.
    Document the two fixes used on Millie: sealed (rubber-insert) collets, and
    a pair of printed TPU rings either side of the collet. Adds STEP files for
    3-13 mm shanks, photos, and links from README, hardware and troubleshooting.
2026-10-19 Clarify which retention ring stops which failure; add TPU print settings
    The lower ring stops 4-8 mm tools being pushed into the collet when the nut
    leaves the spindle thread during unloading; the upper ring stops larger
    tools falling out. Recommend both where possible. Print: generic TPU
    (Sunlu), Bambu Studio standard settings.
2026-10-21 Add ER16 nut holder and parametric generator
    ER16 holder for DIN 6499 hex nuts (M22x1.5, 25 mm A/F). Same module interface as
    the ER20 holder: pocket 25.5 A/F keeps the 0.25 mm/side clearance, same floor and
    2 mm lead-in. The macros and their parameters are unchanged.
    hardware/src/nut_holder.py rebuilds the ER20 holder exactly (zero volume
    difference against the published STEP) and generates ER16.
    Setup guide: ER20 or ER16 hex collet nut; choose the holder when ordering.
